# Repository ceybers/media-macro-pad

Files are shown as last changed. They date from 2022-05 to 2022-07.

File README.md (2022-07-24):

# media-macro-pad

## 📻 Project Description

A wireless macro pad for controlling media playback and volume control.

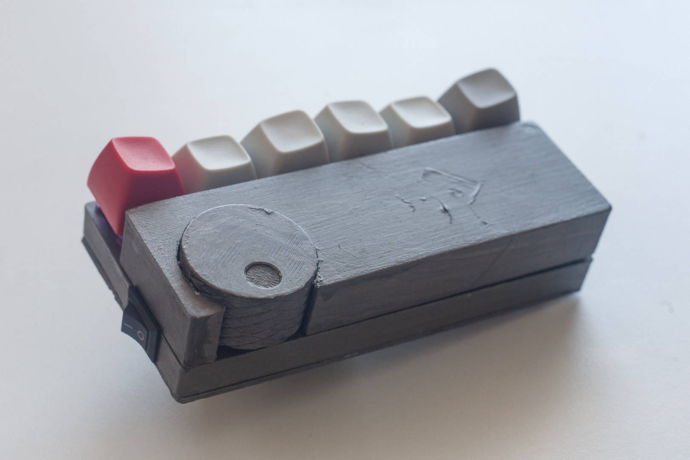
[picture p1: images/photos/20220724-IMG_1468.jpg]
Photo of the macro pad


[More images...](images/gallery.md)

## 🧰 Features

- 6× programmable keys via [MK32 firmware](https://github.com/Galzai/MK32)
- Volume dial
- Connects via BLE
- 500mAh battery
- Charges via USB-C

## 📐 Changes

 - Relocated heatset inserts and bosses
 - Added lugs/lips to help align parts
 - Added support ribs/gussets
 - Changed top shell to use a magnet to stay in place
 - Fixed position of power switch
 - Correct spacing for MCU mounting
 - Removed LED
 - Offset knob to protude from rear of case
## ⚠️ Issues

> Current STL/FreeCAD models are not suitable for actual use!

- Top shell isn't secured firmly with only one magnet
- Lugs on top shell need to be made smaller to fit into slots in middle shell
- Tolerances around cutout for rotary encoder knob are too tight and need filing down

## 🛒 Bill of Materials (BOM)

> ⚠️ BoM is out of date and needs to be updated for latest revision.

| Item | Size | Qty | 
| ---- | ---- | --- |
| [DFrobot FireBeetle ESP32-E](https://www.dfrobot.com/product-2231.html) | N/A | 1 |
| KCD11 Rocker Switch | N/A | 1 | 
| Battery LiPo 500mAh 3.7V | 38.5×29.5×5mm | 1 |
| EC11 Rotary Encoder | 15mm shaft, 4.5mm base | 1 |
| MX switches | N/A | 6 |
| ~~LED, Red~~ |5mm | 1 |
| Resistor | 220 Ohm | 6<sup>1</sup> |
| Heat Set Inserts | M2.5×6mm | 3 |
| Screws | M2.5×6mm | 3 |
| 3D printed shell | N/A | 4 pcs |

1. I used external pull down resistors for this build to work around the peculiarlities that the ESP32 has with internal pull-up/downs when in sleep modes. 

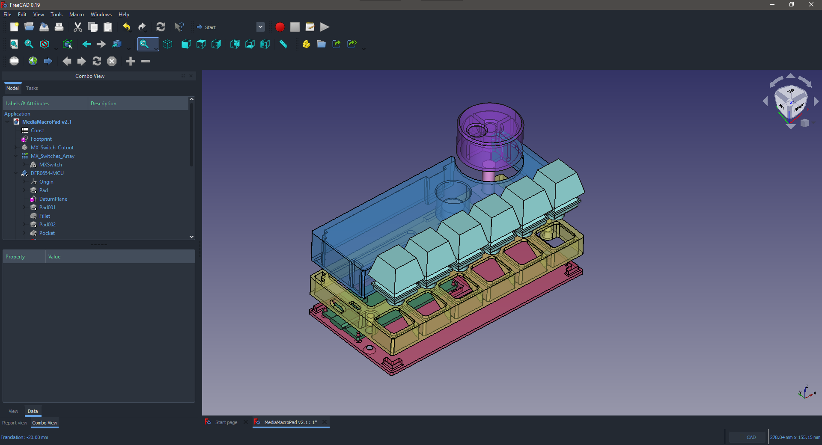
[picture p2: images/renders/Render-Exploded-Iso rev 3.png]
Render of the macro pad

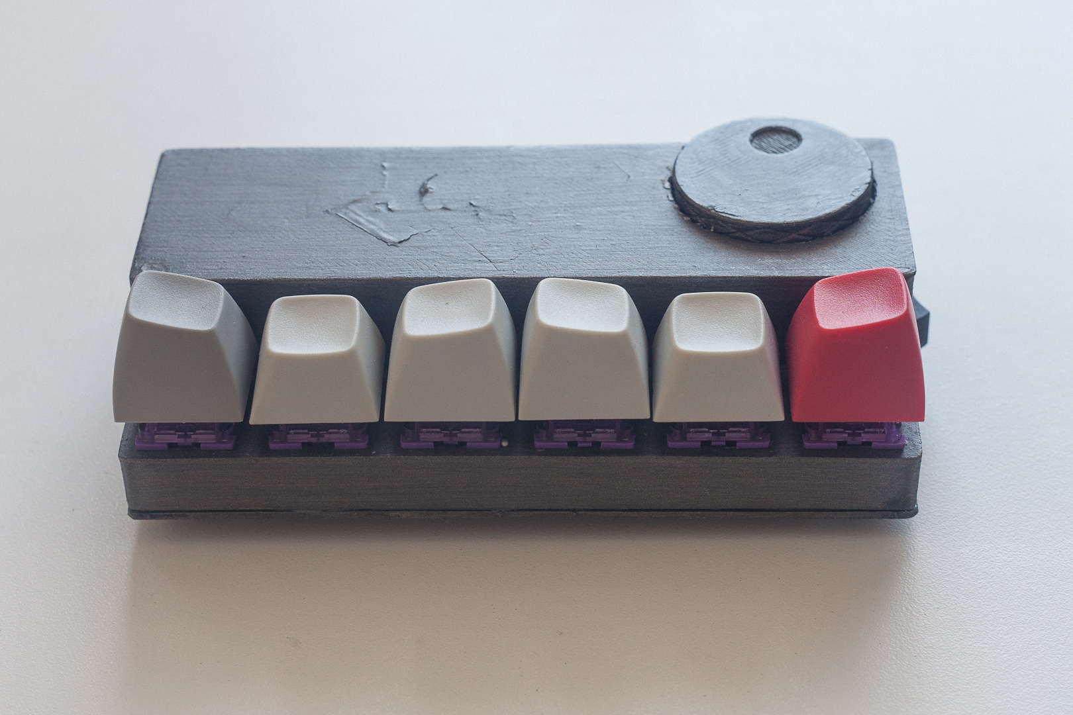
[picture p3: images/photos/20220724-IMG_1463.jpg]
Photo of the macro pad

## 🔗 References

- [MK32 firmware](https://github.com/Galzai/MK32)
- [Firebeetle ESP32-E (DFR0654) wiki](https://wiki.dfrobot.com/FireBeetle_Board_ESP32_E_SKU_DFR0654)
- [EspressIf API Reference](https://docs.espressif.com/projects/esp-idf/en/latest/esp32/api-reference/index.html)

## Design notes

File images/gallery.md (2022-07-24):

# Gallery

## Photos (rev 3)
Front
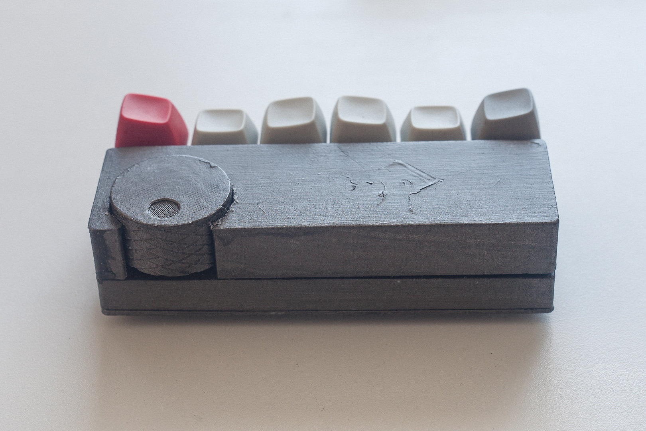
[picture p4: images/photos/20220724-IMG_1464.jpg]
Read

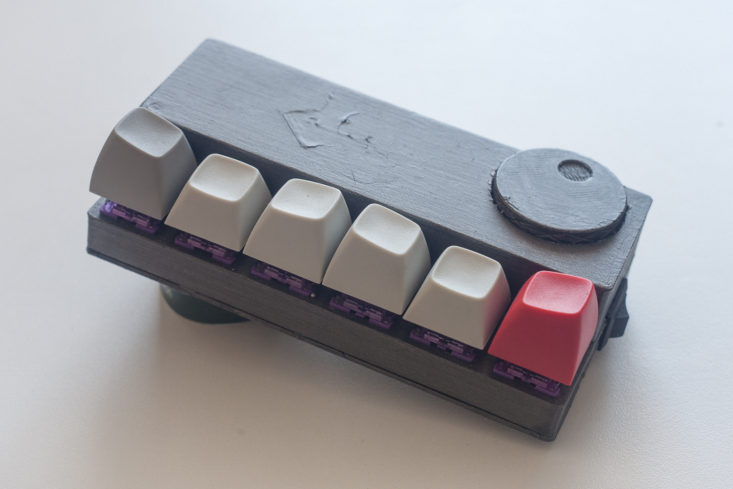
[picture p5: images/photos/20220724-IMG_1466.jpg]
Front angle

Rear angle

## CAD Screenshots (rev 3)
Exploded
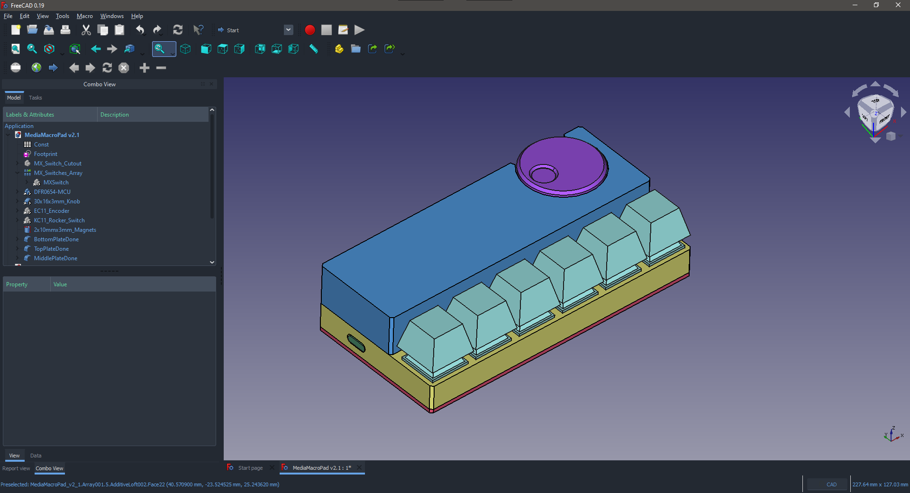
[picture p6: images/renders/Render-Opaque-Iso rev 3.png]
Opaque

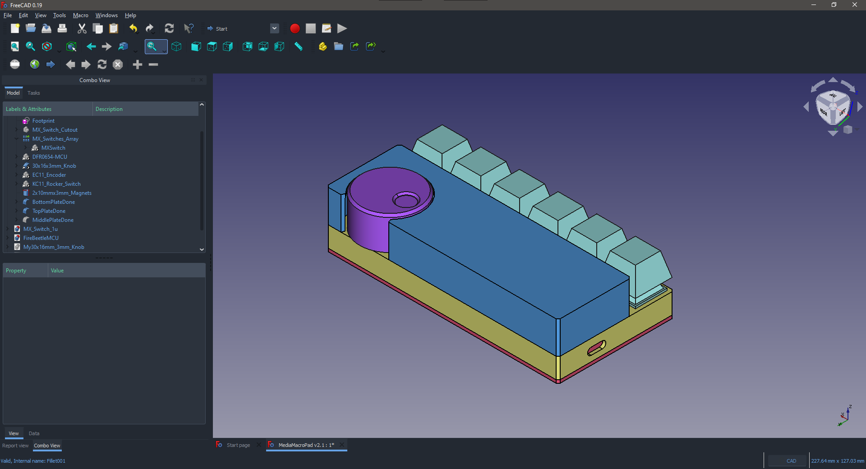
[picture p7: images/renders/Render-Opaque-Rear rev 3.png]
Rear

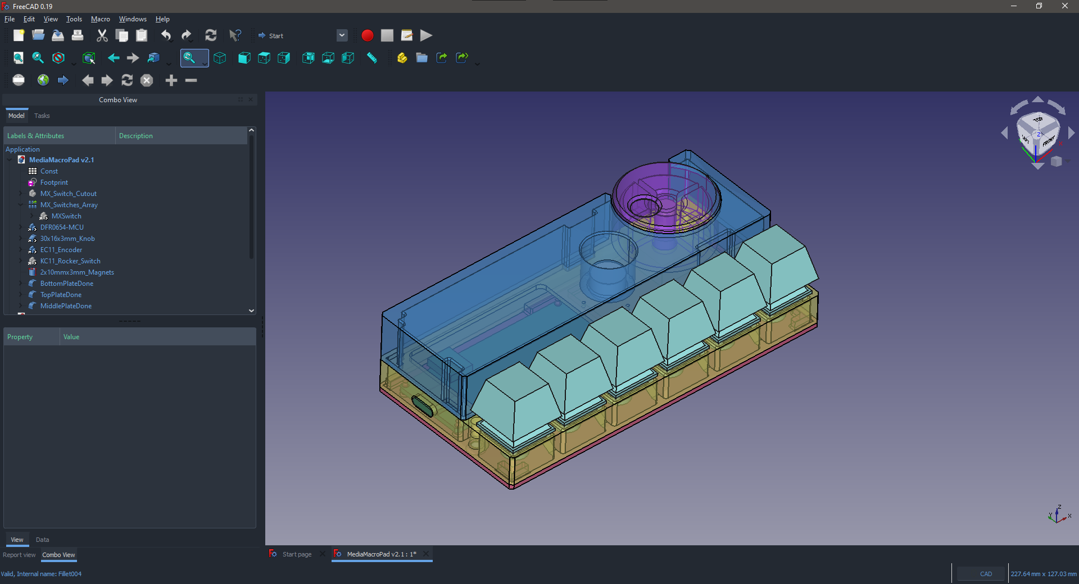
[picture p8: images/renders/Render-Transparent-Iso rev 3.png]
Transparent


## Photos (rev 1)

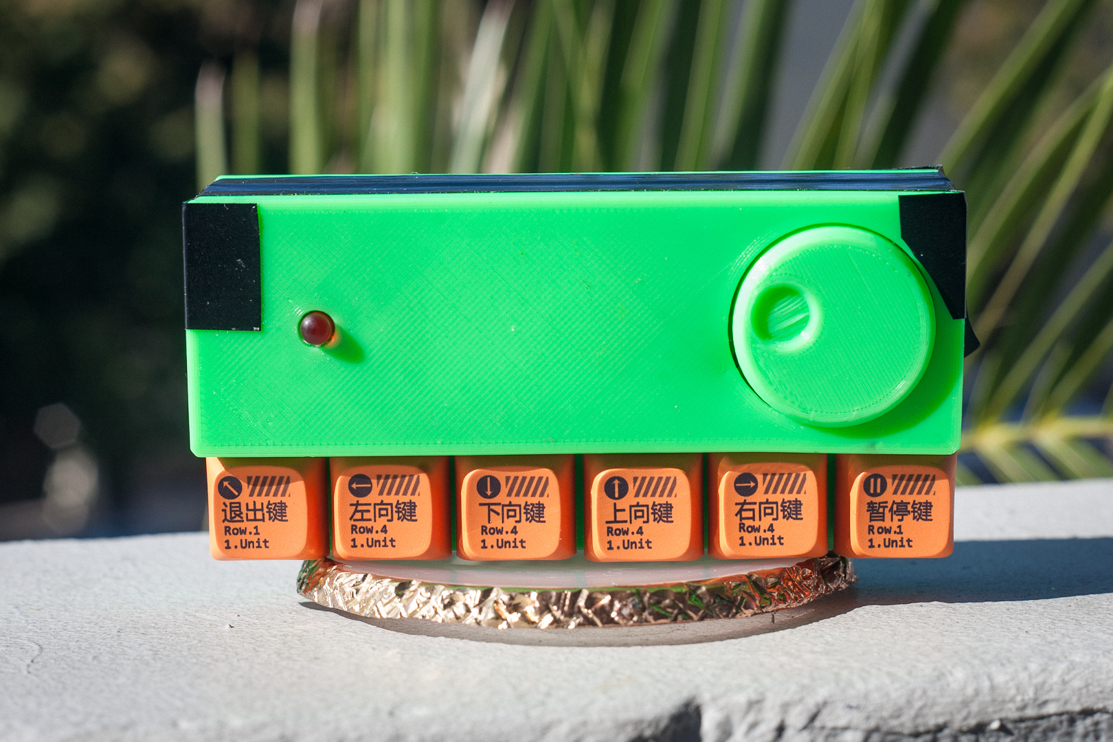
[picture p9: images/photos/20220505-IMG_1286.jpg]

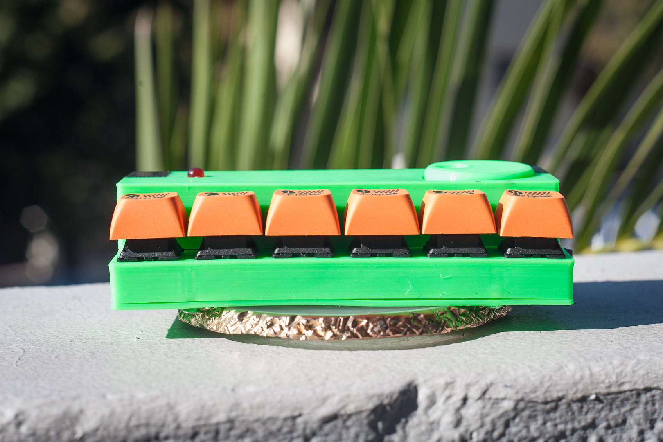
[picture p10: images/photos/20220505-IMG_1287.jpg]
Side

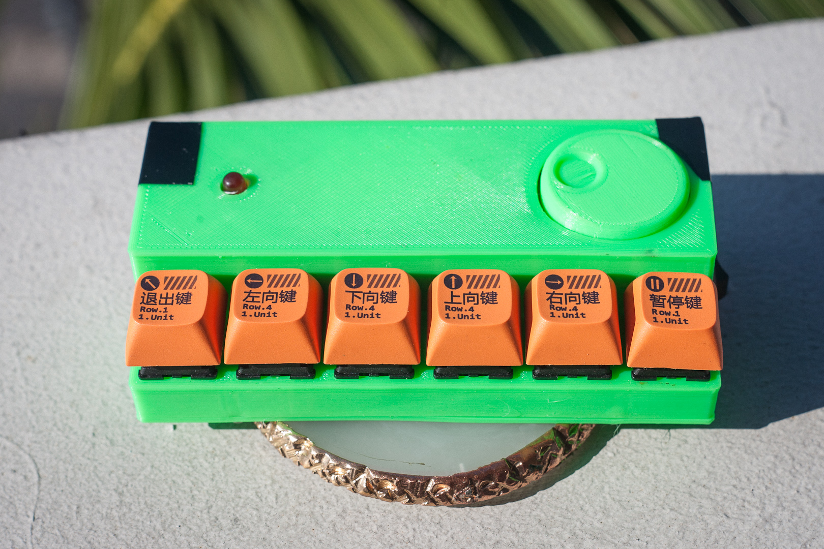
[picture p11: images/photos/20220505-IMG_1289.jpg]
Front, angled

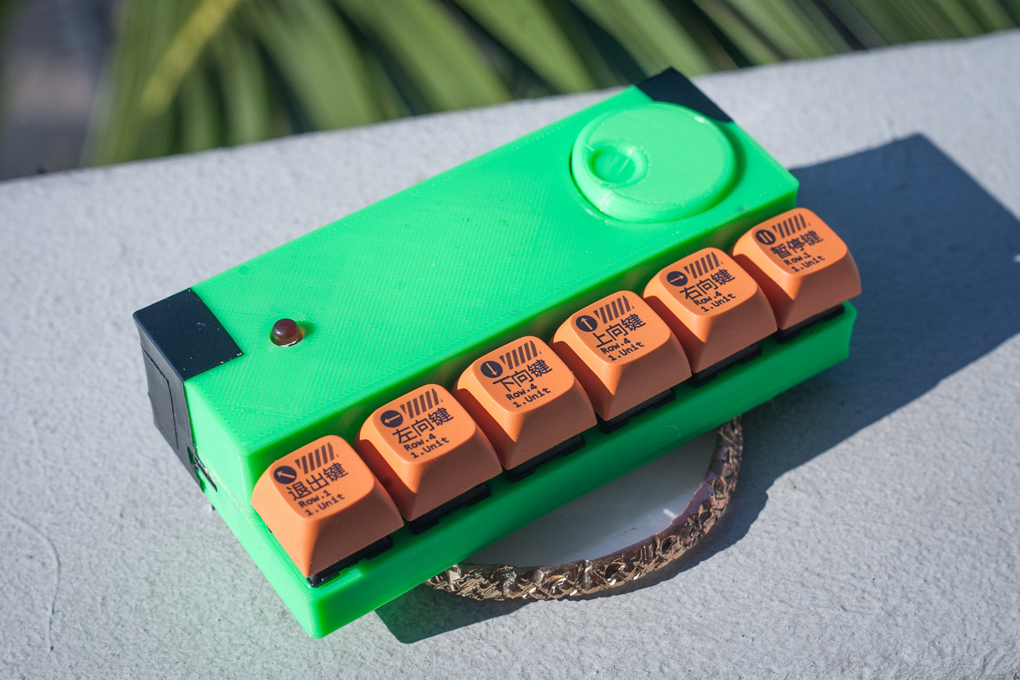
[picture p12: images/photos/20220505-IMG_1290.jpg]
Rotated, USB-C

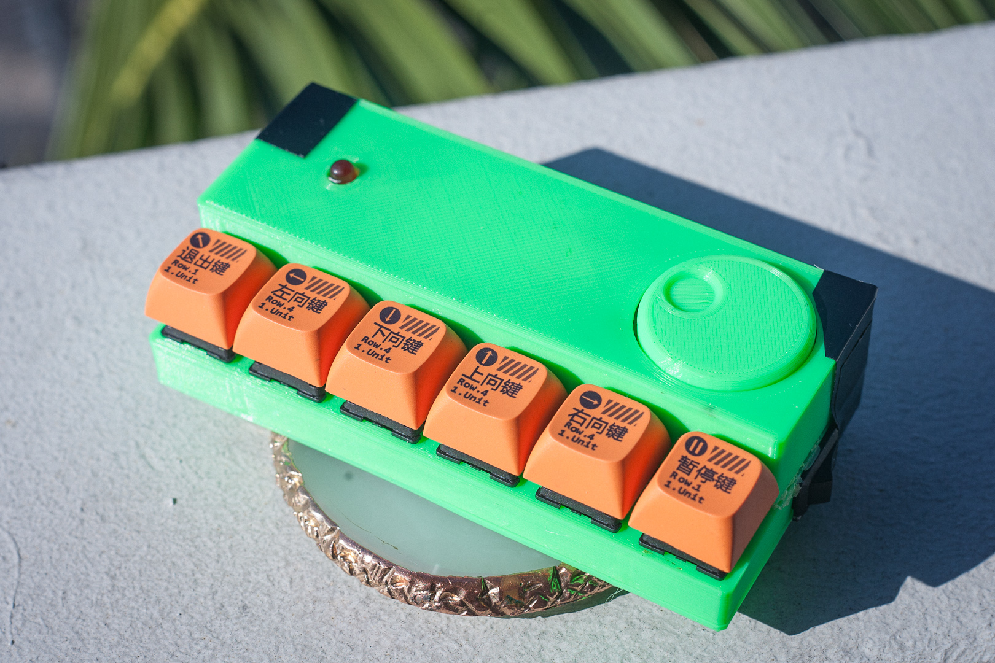
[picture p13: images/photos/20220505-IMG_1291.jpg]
Rotated, power

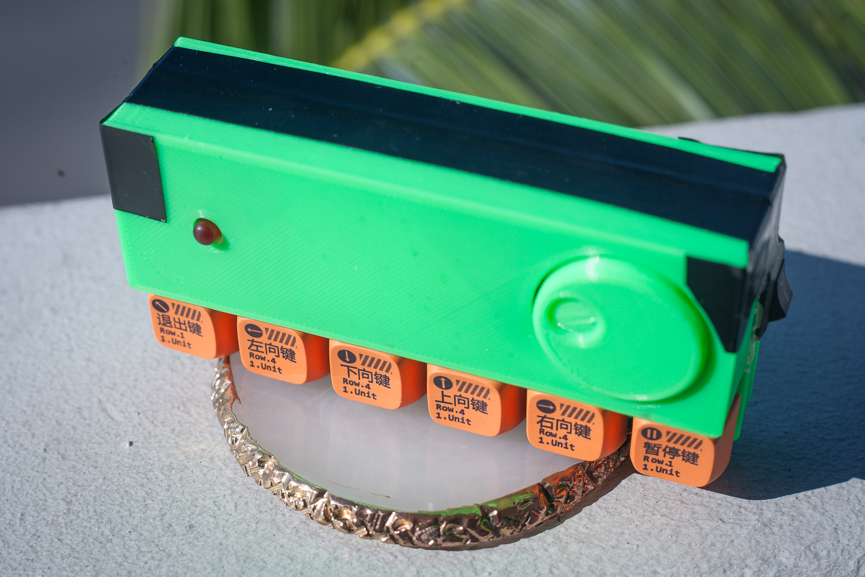
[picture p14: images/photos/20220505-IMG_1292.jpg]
Vertical


## CAD Screenshots (rev 1)

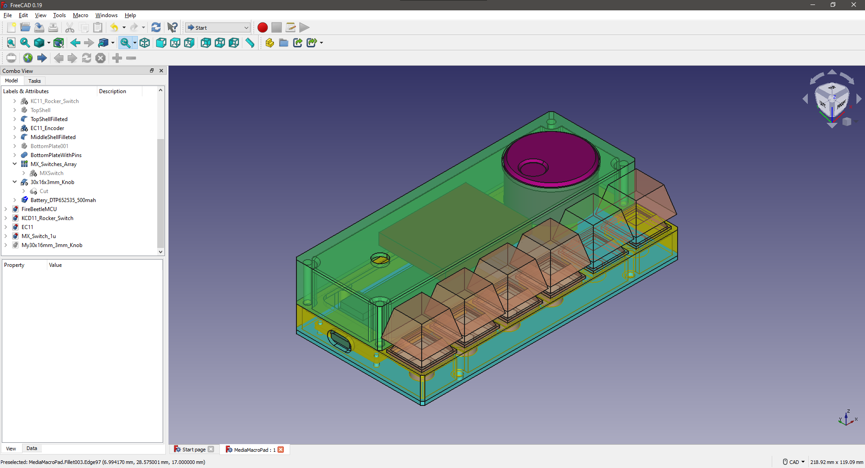
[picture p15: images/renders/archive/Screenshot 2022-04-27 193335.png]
Assembled, Transparent

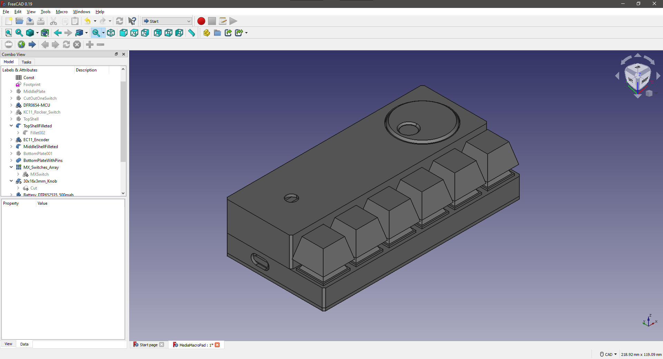
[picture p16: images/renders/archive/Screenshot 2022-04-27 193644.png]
Assembled, Opaque

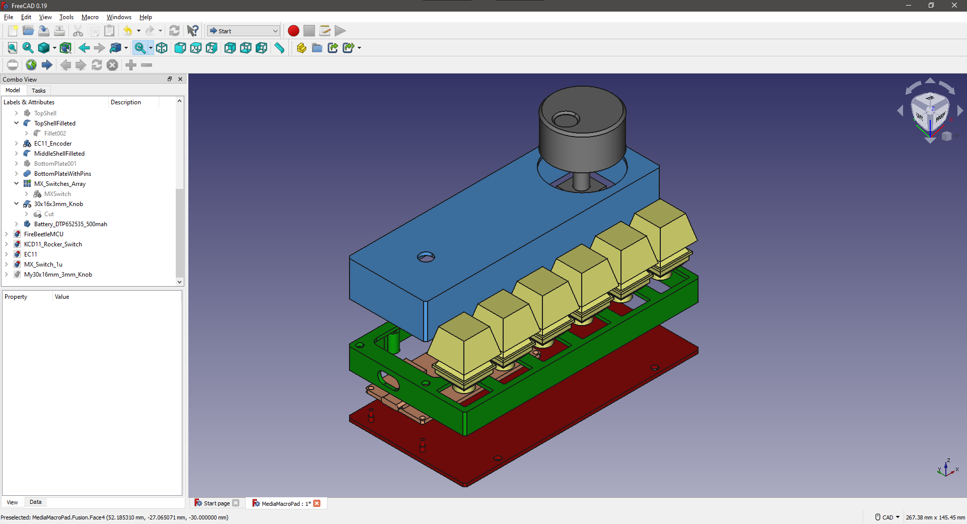
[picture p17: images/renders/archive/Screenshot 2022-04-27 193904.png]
Exploded, Top

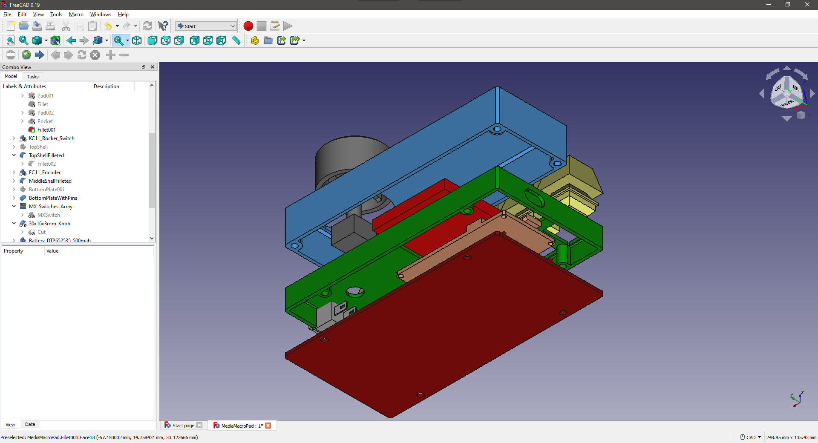
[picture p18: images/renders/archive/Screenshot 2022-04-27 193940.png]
Exploded, Bottom


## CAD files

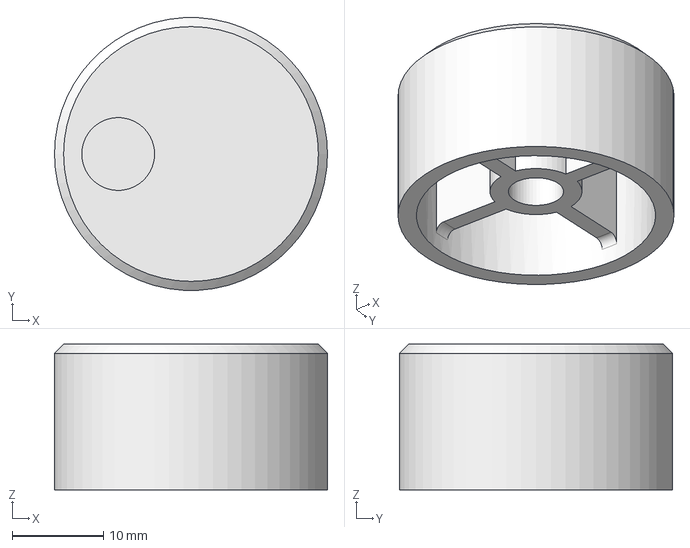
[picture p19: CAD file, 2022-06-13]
freecad/My30x16mm_3mm_Knob.FCStd
30.0 x 30.0 x 16.0 mm

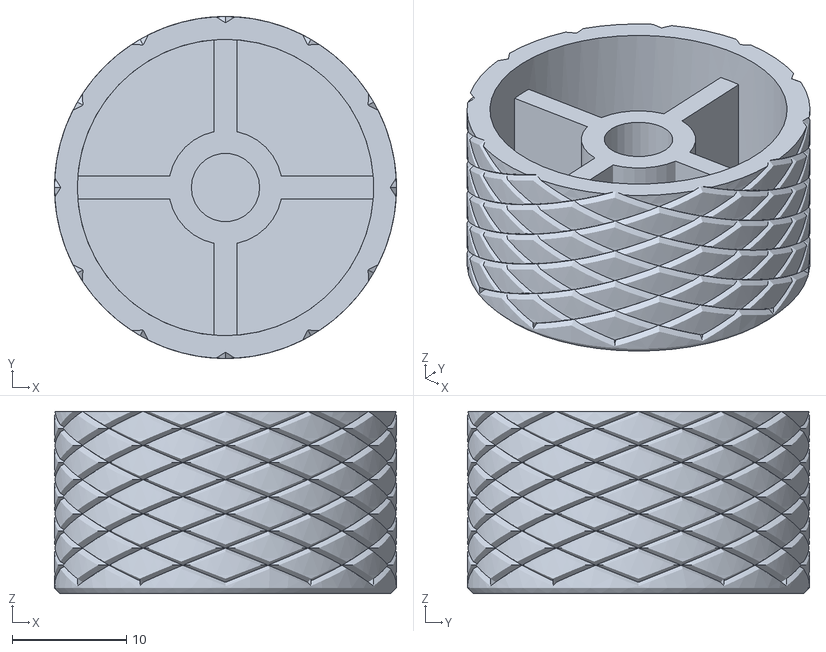
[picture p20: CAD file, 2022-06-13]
stl/Rotary_Encoder_Knob.stl
30.0 x 30.0 x 16.0

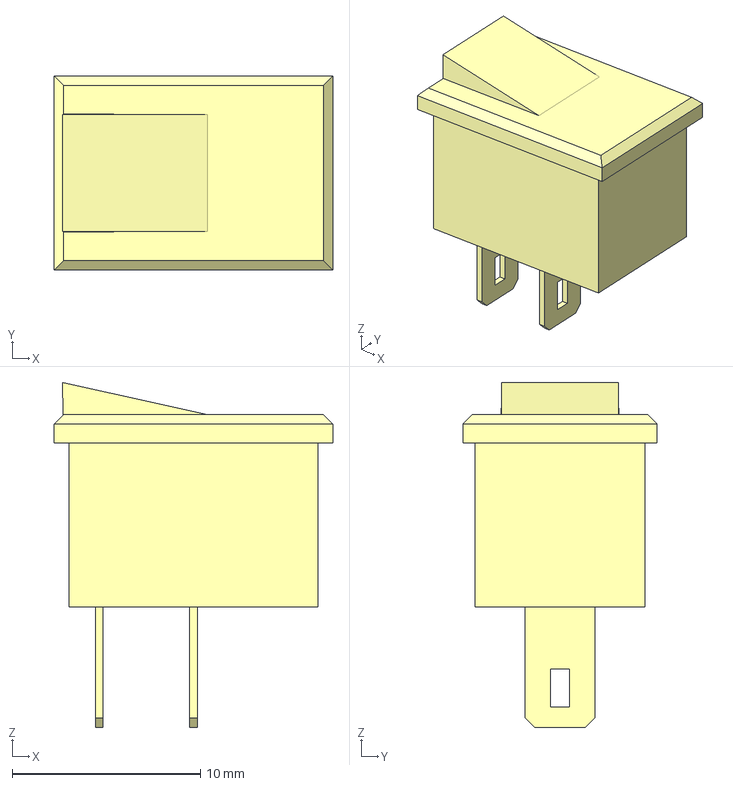
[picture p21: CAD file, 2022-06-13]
freecad/KCD11_Rocker_Switch.FCStd
14.8 x 10.3 x 18.3 mm

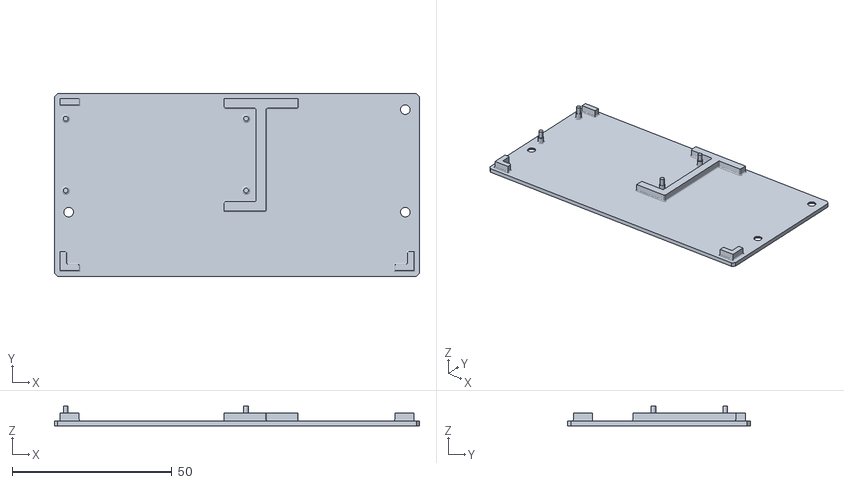
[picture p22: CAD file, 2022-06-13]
stl/Case6x1-BottomPlate.stl
114.3 x 57.2 x 6.14

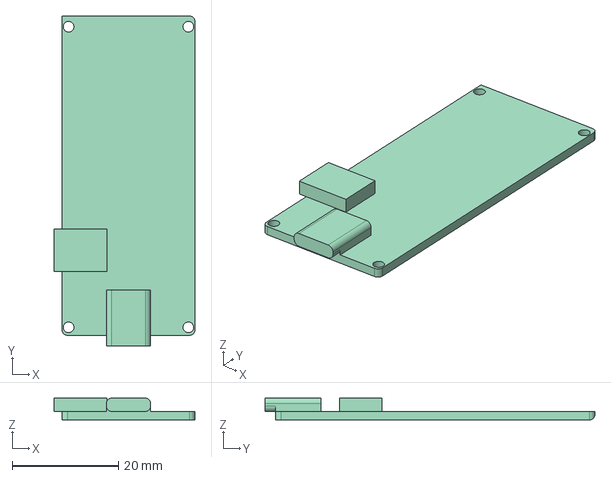
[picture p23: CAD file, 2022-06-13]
freecad/FireBeetleMCU.FCStd
26.5 x 62.0 x 4.10 mm

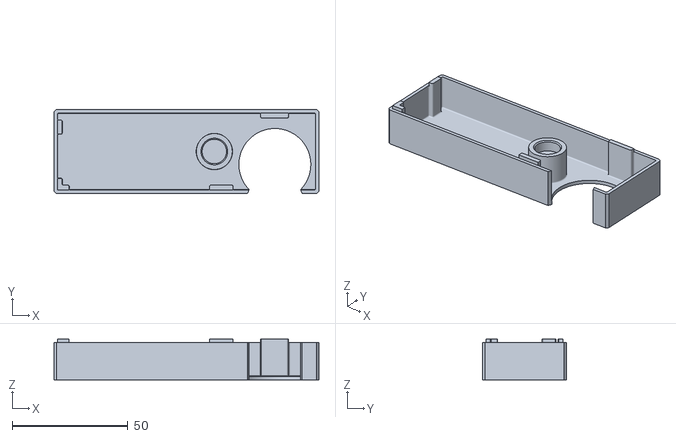
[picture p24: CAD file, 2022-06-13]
stl/Case6x1-TopShell.stl
114.3 x 36.1 x 17.5

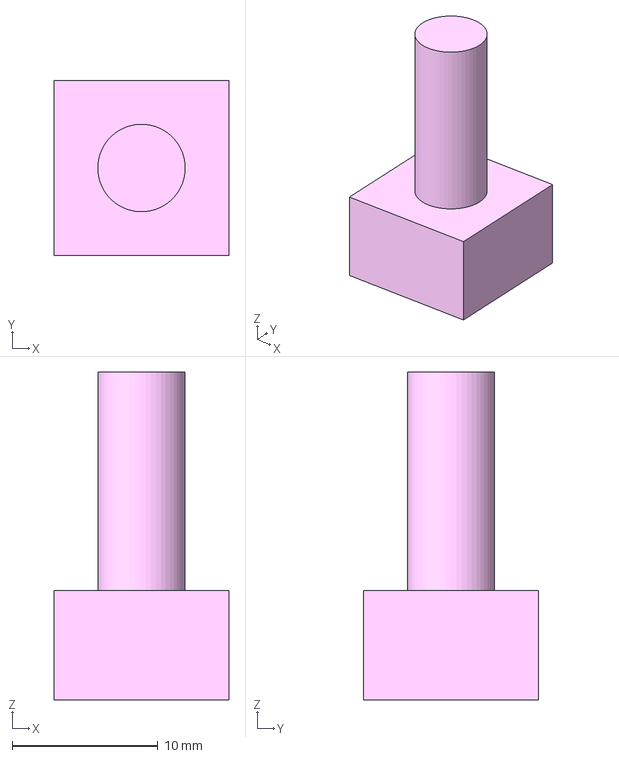
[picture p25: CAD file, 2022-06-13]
freecad/EC11.FCStd
12.0 x 12.0 x 22.5 mm

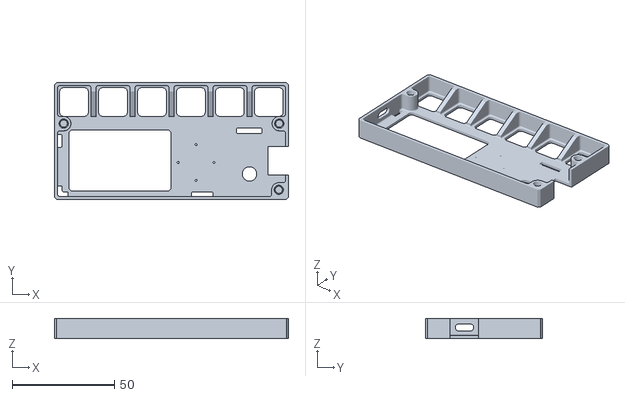
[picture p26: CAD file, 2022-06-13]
stl/Case6x1-MiddleShell.stl
114.3 x 57.2 x 10.0

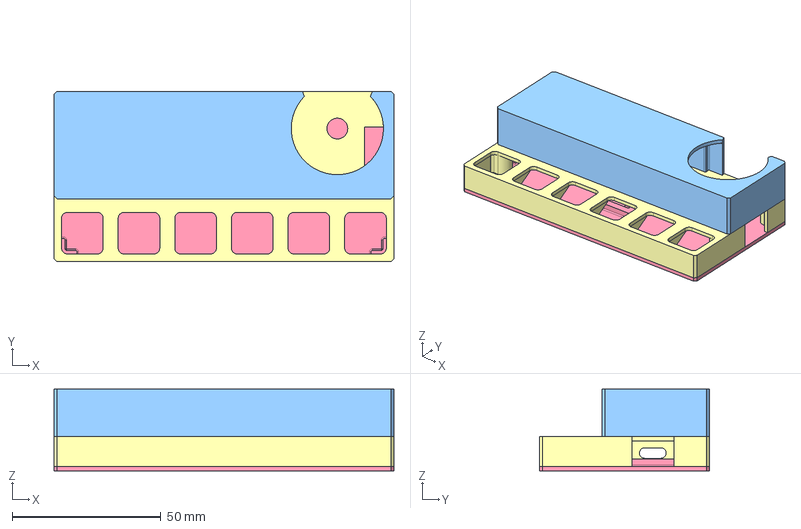
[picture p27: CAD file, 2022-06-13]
freecad/Case6x1.FCStd
114.3 x 57.2 x 27.5 mm
2x10mmx3mm_Magnets
BottomPlateDone
TopPlateDone

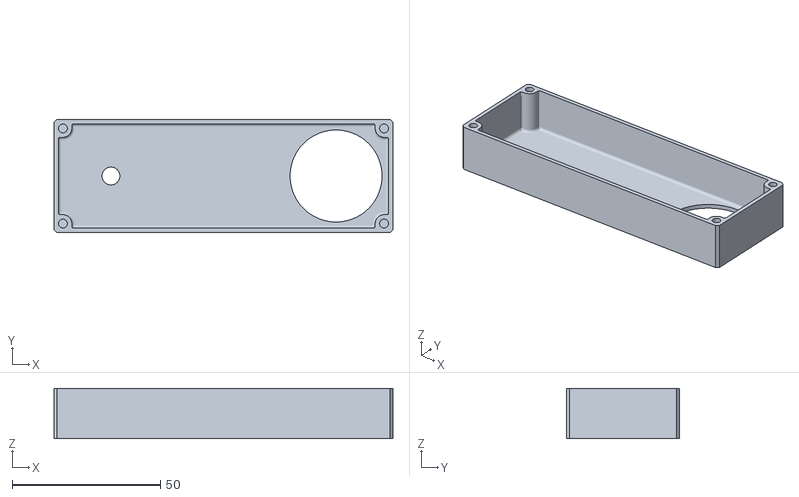
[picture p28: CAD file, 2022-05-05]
stl/MacroPad_Top.stl
114.3 x 38.1 x 17.0

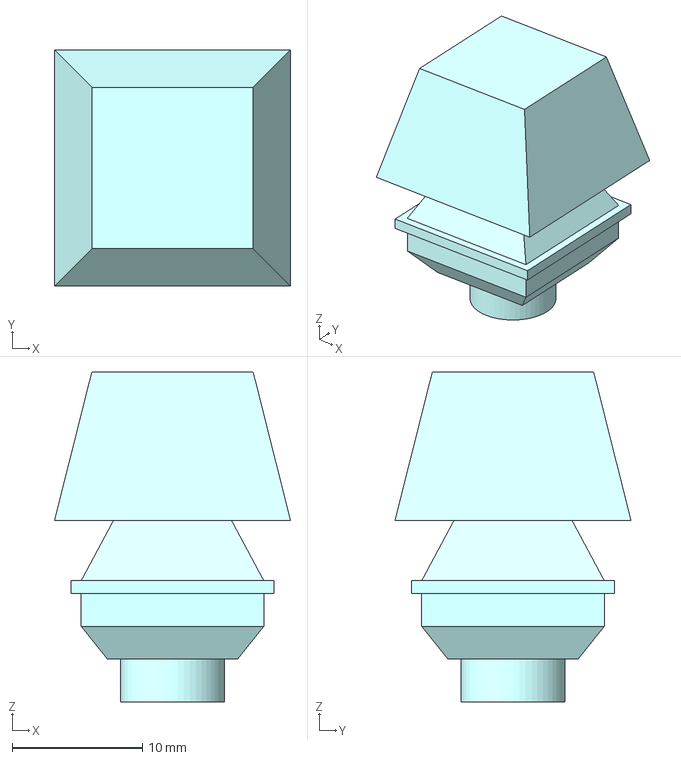
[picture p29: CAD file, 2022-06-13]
freecad/MX_Switch_1u.FCStd
18.1 x 18.1 x 25.3 mm

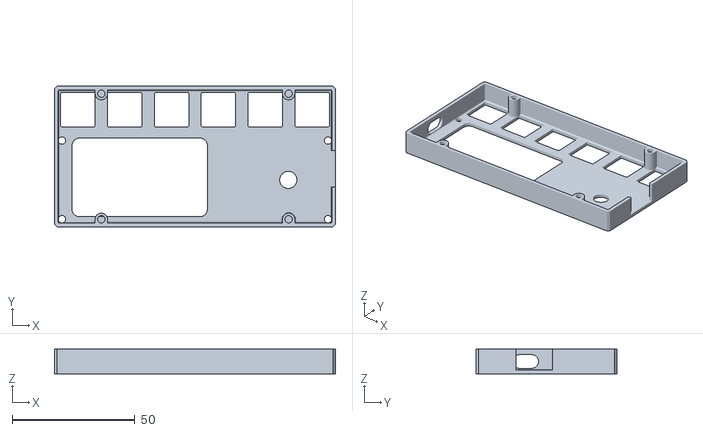
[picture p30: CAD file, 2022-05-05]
stl/MacroPad_Middle.stl
114.3 x 57.2 x 10.0

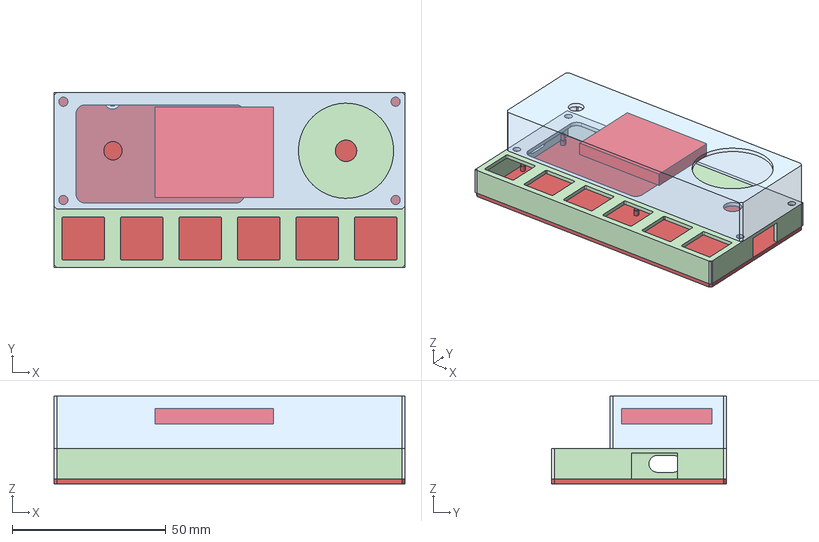
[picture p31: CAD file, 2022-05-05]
freecad/MediaMacroPad.FCStd
114.3 x 57.2 x 28.5 mm
MiddlePlate
TopShellFilleted
MiddleShellFilleted
BottomPlateWithPins
Battery_DTP652535_500mah

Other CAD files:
stl/MacroPad_Bottom.stl
freecad/archive/MX_Switch_1u.FCStd
stl/archive/MacroPad_Bottom.stl
freecad/archive/EC11.FCStd
freecad/archive/FireBeetleMCU.FCStd
freecad/archive/KCD11_Rocker_Switch.FCStd
freecad/archive/My30x16mm_3mm_Knob.FCStd
stl/RotaryEncoderKnob.stl
stl/archive/RotaryEncoderKnob.stl
